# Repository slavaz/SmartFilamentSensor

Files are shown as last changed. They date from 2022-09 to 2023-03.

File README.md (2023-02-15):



Smart Filament Sensor
===

The project describes how to make by your own pretty smart filament sensor for your 3D printer.

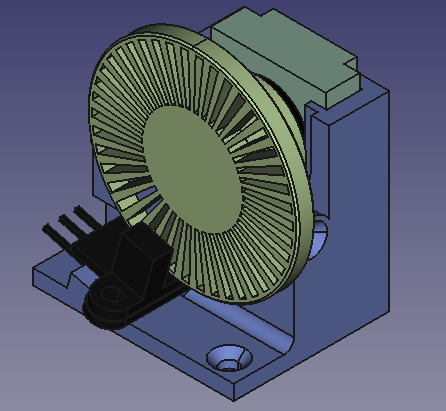
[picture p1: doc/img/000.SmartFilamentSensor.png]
Assembly Engine Part


For getting more information please see [doc/README](doc/README.md) file

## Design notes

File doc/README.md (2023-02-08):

About
===

The Smart Filament Sensor it's just my attempt to implement fully backward compatible sensor with my 'Creality CR10 Smart' 3D printer. I know about existing smart sensors, but almost all of these sensors require flashing by own-compiled firmware with changing sensor settings. My sensor is fully compatible with stock filament sensor and doesn't require any own-compiled firmwares (but you may use the firmwares as well, and without any restrictions).

Main idea
---

So, there is a stock sensor for my printer:

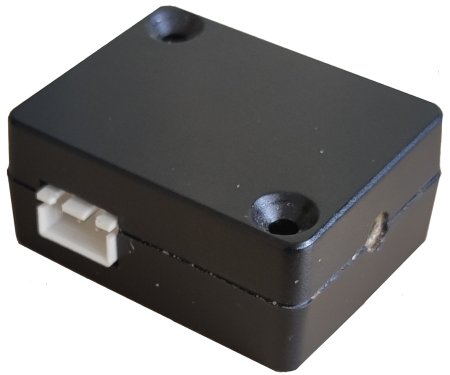
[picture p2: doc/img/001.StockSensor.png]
Stock sensor


The sensor is very simple: has just a microswitch inside and has only one function: to alarm if the microswitch isn't pressed  by a filament. To be honest, the sensor has a optical sensor with some small circuit inside, but it implemented like a simple and stupid micriswitch. In general, it's okay, but there are few cases when it isn't enough:

- The filament may stuck for some reasons. Eg. it may be get tangled in a coil before a sensor or it may be deformed and jammed by feed gear in extruder due to a lot of retractions in small amount of time. In this case the printer continues to print 'in air'. Probably, after some time filament may be  continued to move again  and you will see a lot of 'scary plastic hairs' instead of nice and well-printed model...

- A diameter of the filament may be unstable (especially for self-made filaments like in my case). Or the filament may be severely bent or dented. In this case  microswitch may be switched off due to insufficient filament pressure on the lever and your 3D-printer may think that filament ended, and the printer stucks until you pass 'Changing filement' ceremony. 

So for detecting not only 'filament ended' events, need to recognize only one case: extruder works but filament doesn't move. This case covers all what I need, include 'filament ended' event. And my Smart Filament Sensor recognizes exactly this case.

Prerequirements
===

The Smart Filament Sensor has two movement sensors: one for a filament, and second one - for a motor in extruder. Stock extruder looks like:

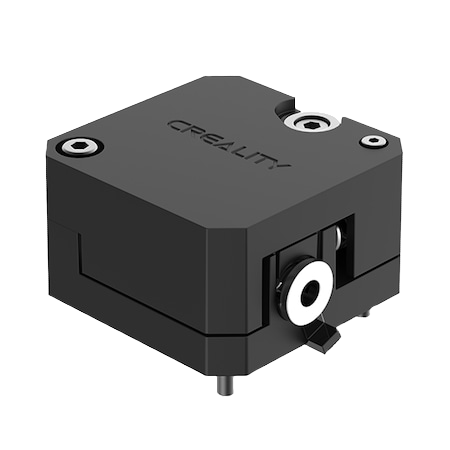
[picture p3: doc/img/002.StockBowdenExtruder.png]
Stock bowden extruder


With this extruder we don't have ability to access to motor shaft (as we need to recognize rotation) - the motor shaft is placed inside fully closed box. So in my case, I've replaced the stock extruder by this:

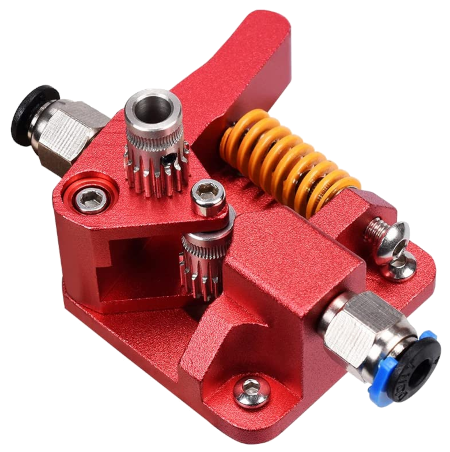
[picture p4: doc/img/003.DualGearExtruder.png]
Dual gear extruder


If you want to buy the same extruder, you may search it in Internet by '[dual gear extruder](https://www.google.com/search?q=dual+gear+extruder)' query. 

The extruder gives us an access to the top of a motor shaft so now it's possible to recognize a rotation of the motor by Smart Filament Sensor.

Requirements
===

Hardware
---

In general, all what I bought is:
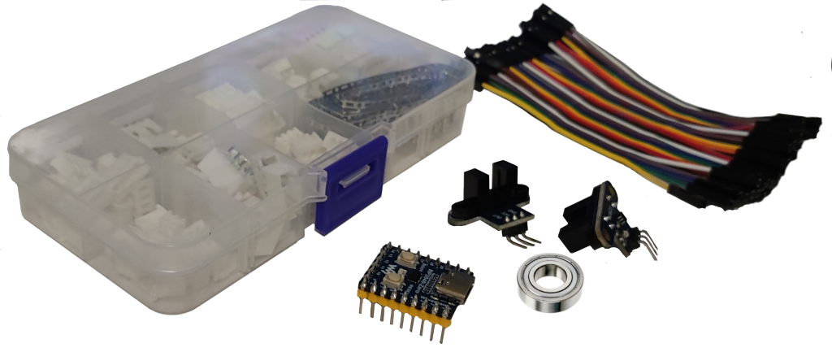
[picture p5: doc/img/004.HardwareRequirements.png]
Hardware Requirements


- RP2040-Zero
- Two movement optical sensors
- a set of wires
- XH2,54 Connector Terminal Kit... to be honest, I only need one 3pin 'mother' connector but it's hard to find just one, so it's easy to buy a kit... maybe it will come in handy in my other projects, yeah
- bearing 625ZZ 5x16x5 mm

All these stuff I bought on AliExpress. I don't sure is it makes sence to post links here as these links may be outdated and you might end up with funny '404 not found' page... but there are links nonetheless:
- https://pl.aliexpress.com/item/32735930193.html
- https://pl.aliexpress.com/item/1005004310502426.html
- https://pl.aliexpress.com/item/32909050779.html
- https://pl.aliexpress.com/item/1005004281549886.html
- https://www.aliexpress.com/item/32719052164.html
  
If any of the links don't work, please let me know via a pull request, huh.

You may already have the following stuff:

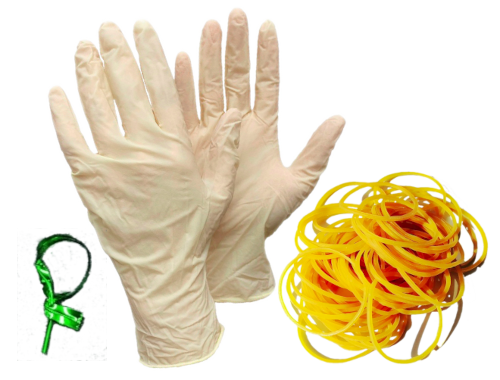
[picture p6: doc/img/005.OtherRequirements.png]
other requirements

- latex medical gloves (you may buy it in any pharmacy or a shop)
- elastic rubber bands (frankly speaking, I never bought it. The rubber bands always present in my house, I don't know from)
- disposable packing wire (we usually throw it in the trash can). It can be found when you buying new electrical products with power wires - the packaging wire prevents twisted wires from unwinding inside the package.

In additional, it would be great if you knew a little about the soldering iron...

And, of course, it would be great if you had a 3D printer as some parts of this project need to be 3D printed.

Software
---

If you only want to assembly the Smart Filament Sensor, then you don't need any additional software. Download only the [latest releases](../releases/)  files and follow [step-by-step](Step-by-step.md) instruction.

If you want to contribute the project (eg, if you want to improve existing source codes or to add support of STM32 or Arduino boards), please follow [Development](Development.md) instructions

Advanages
---
Better control of filament moving

Disadvantages
---

Periodically need to clean up rubber ring as filament may slippage due to lost adgesion. To avoid it, you can use some kind of 'Filament cleaners' like https://www.thingiverse.com/thing:2440593 or https://www.thingiverse.com/thing:190118

TODO
---
To design in FreeCAD nice box for RP2040Zero. As for me, it works as well and functionality is enough, so if you feel that it isn't perfect and you need to show off your 3D-printer with the SmartSensor to you friends- feel free to design the box and create pull request... I'm so lazy to do the last step ;)

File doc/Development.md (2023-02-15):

It's good to see you here at the page as it means, you have posible interest in contributing to the project... but probably not, who knows.
Anyway, at the page you may find instructions how to set up build environment for the project.

Raspberry Pi Pico SDK
===

Install in some folder Pico SDK from here: https://github.com/raspberrypi/pico-sdk

I did it by the command:

`git clone https://github.com/raspberrypi/pico-sdk.git`

and followed instructions from the README.md file of the project.

Nothing hard here, just a reminder: do not forget to define environment variable `PICO_SDK_PATH`

And yet another note: I have Fedora, but instructions from the project describe a way for Debian-based distros, so there are commands to install all needed packages under RPM-based distros:

`sudo dnf install -y cmake arm-none-eabi-binutils-cs  arm-none-eabi-gcc-cs arm-none-eabi-gcc-cs-c++ arm-none-eabi-newlib`

Other tools
===

You also need to install GoogleTest and Freecad.

deb-based distros:
`sudo apt install googletest google-mock libgtest-dev libgmock-dev freecad`

RPM-based distros:

`sudo dnf -y install gtest-devel gmock-devel freecad`

Getting sources
===

It's simply:

`mkdir -p ~/myprojects`

`cd ~/myprojects`

`git clone https://github.com/slavaz/SmartFilamentSensor.git`

`cd SmartFilamentSensor`

Build project
===
`cmake -B build`

`cd build`

`make all test`

If you want to get a tarball with assebmled files, run the command:

`make package`

after it, you will have a tarball into `build/package` folder.

The tarball contains a firmware binary file and STL-files with 3D models.

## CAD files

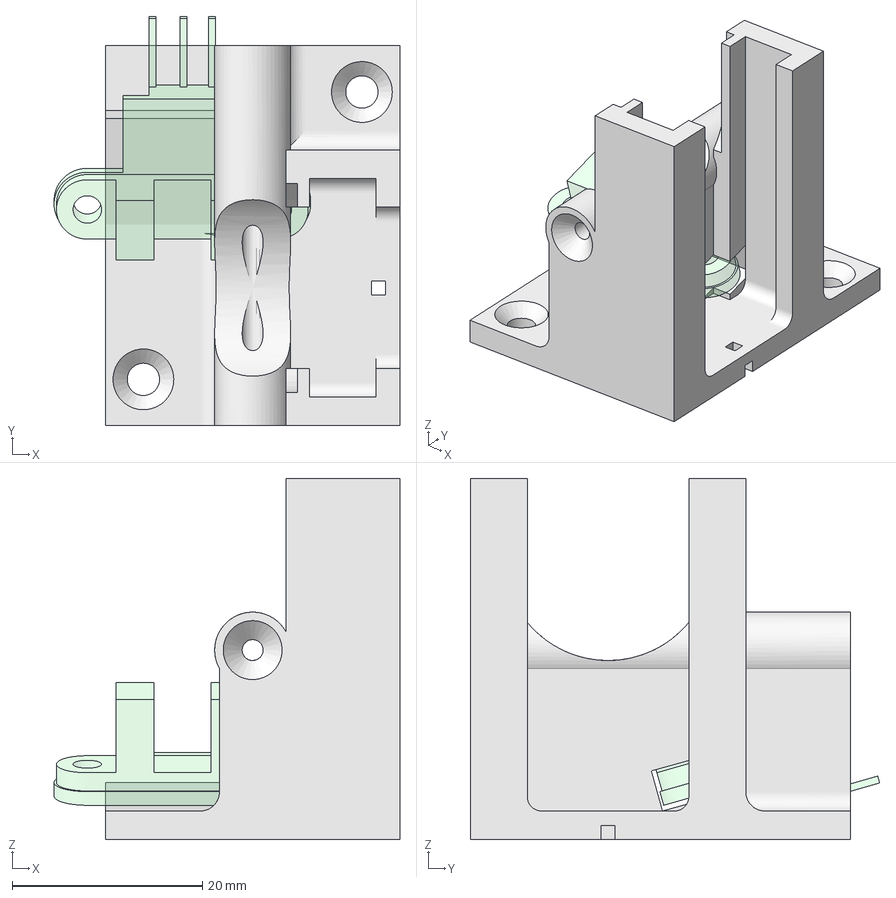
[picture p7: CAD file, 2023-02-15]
3dmodels/CrealityCR10Smart_DualGearExtruder/MainBody.FCStd
36.4 x 43.1 x 38.0 mm
MainBody
MovementSensor (Meshed)

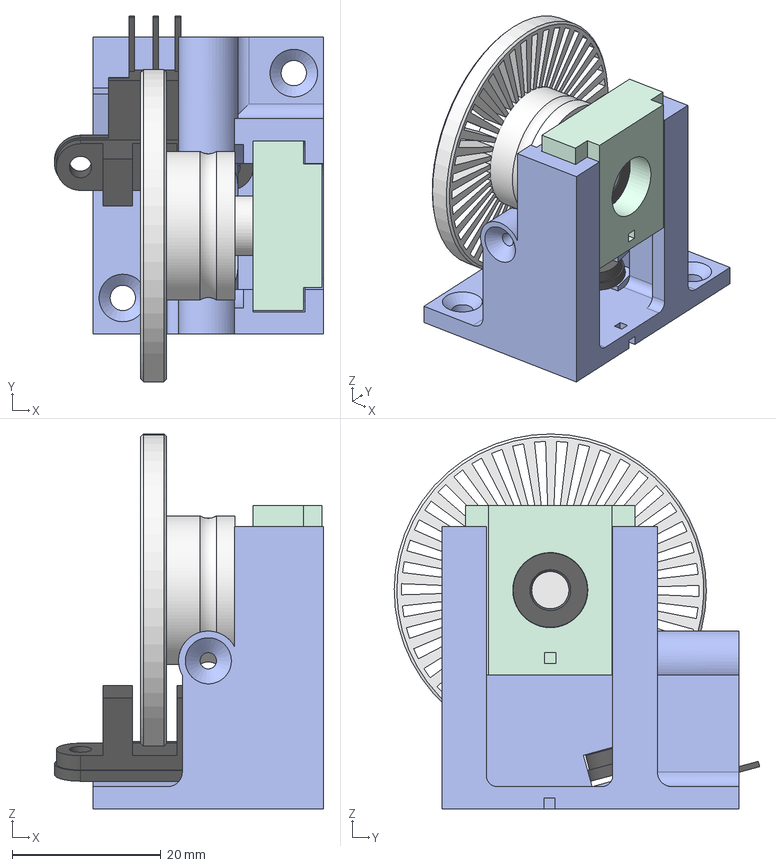
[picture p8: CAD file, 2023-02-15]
3dmodels/CrealityCR10Smart_DualGearExtruder/Assembly-FilamentSensor.FCStd
36.2 x 49.2 x 50.4 mm
MainBody_001
BearingSupport_001
Bearing_001
FilamentWheel_001
MovementSensor_001

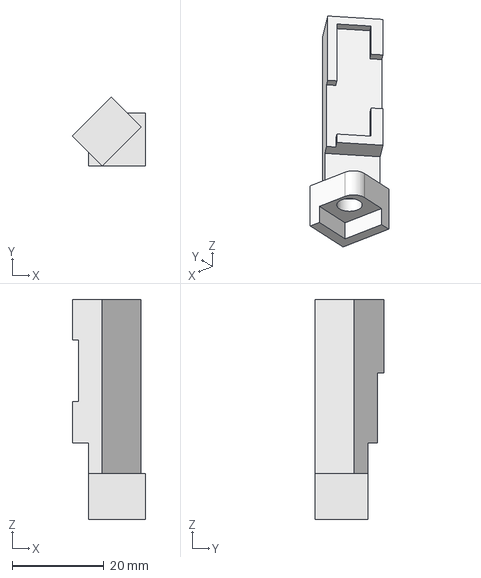
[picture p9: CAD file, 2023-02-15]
3dmodels/CrealityCR10Smart_DualGearExtruder/EngineMainBody.FCStd
16.0 x 15.0 x 48.0 mm

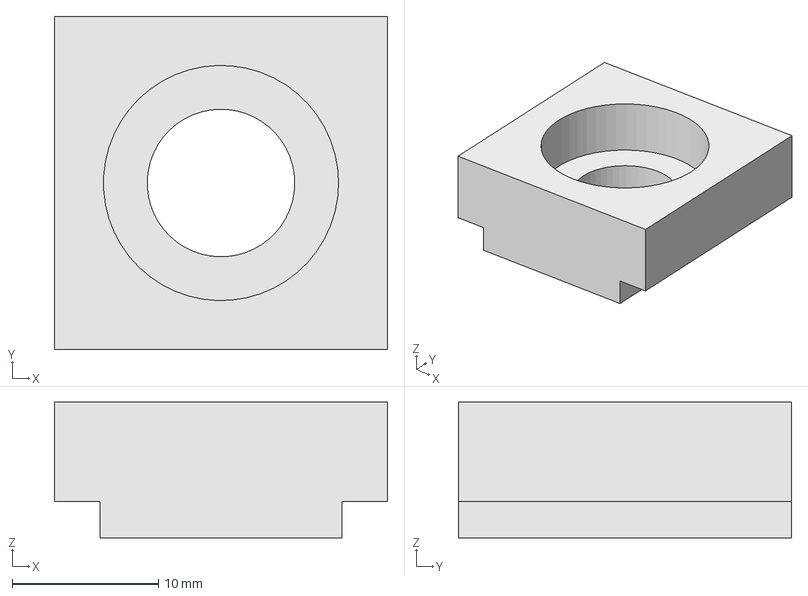
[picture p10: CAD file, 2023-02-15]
3dmodels/CrealityCR10Smart_DualGearExtruder/BearingSupport.FCStd
22.8 x 22.8 x 9.30 mm

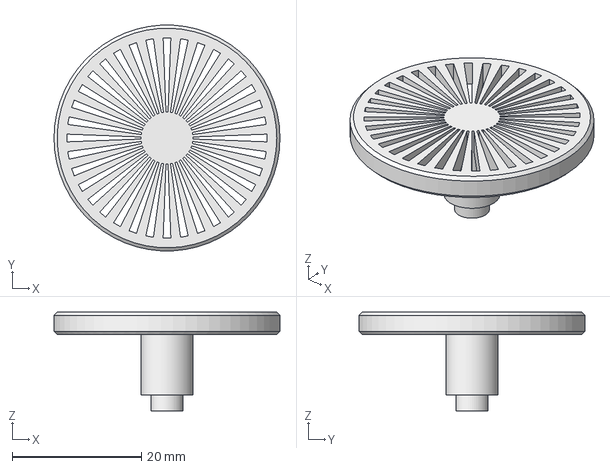
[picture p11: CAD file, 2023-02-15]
3dmodels/CrealityCR10Smart_DualGearExtruder/EngineShaftWheel.FCStd
35.0 x 34.9 x 15.3 mm

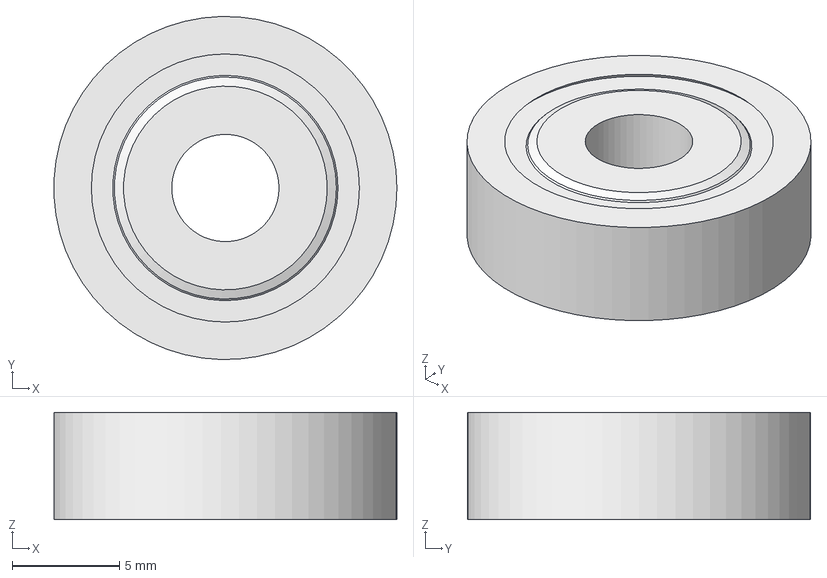
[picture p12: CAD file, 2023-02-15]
3dmodels/CrealityCR10Smart_DualGearExtruder/Bearing.FCStd
16.0 x 16.0 x 5.00 mm

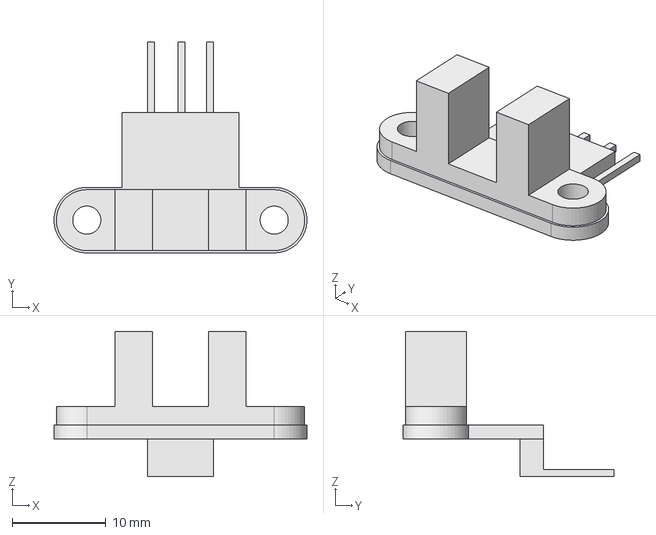
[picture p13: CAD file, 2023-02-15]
3dmodels/CrealityCR10Smart_DualGearExtruder/MovementSensor.FCStd
27.0 x 22.5 x 15.5 mm

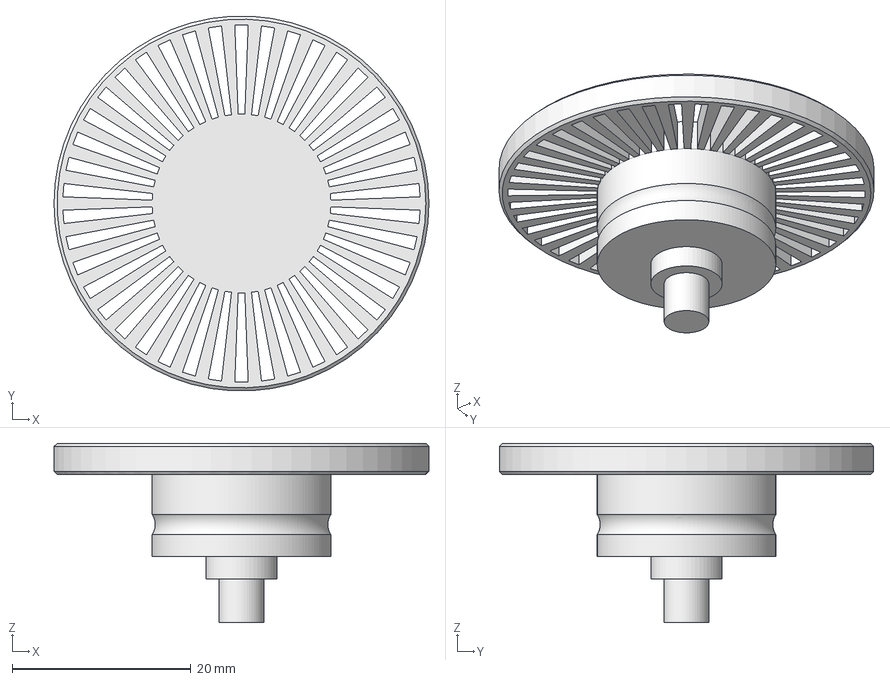
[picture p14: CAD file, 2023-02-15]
3dmodels/CrealityCR10Smart_DualGearExtruder/FilamentWheel.FCStd
42.0 x 41.9 x 20.1 mm

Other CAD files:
3dmodels/CrealityCR10Smart_DualGearExtruder/SharedParameters.FCStd

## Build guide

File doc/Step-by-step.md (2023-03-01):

Step-by-step instruction
===
I suppose, you have bought all needed stuff and downloaded all needed files from the project at this moment, isn't it? If no - please read the [manual](README.md) again more carefully... :)

3D prining
---

So first step is: to 3D-print all parts of the SmartFilamentSensor. I  printed these parts by 0.4 mm nozzle:

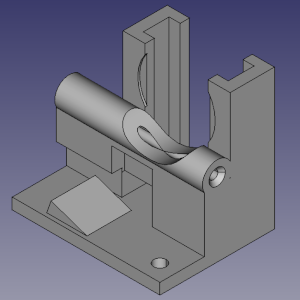
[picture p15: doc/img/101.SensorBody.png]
Sensor body

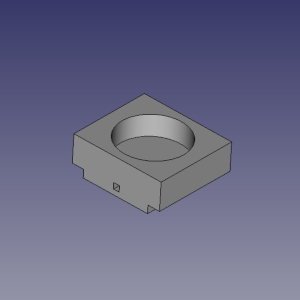
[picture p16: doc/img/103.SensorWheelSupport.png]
Sensor Wheel Support

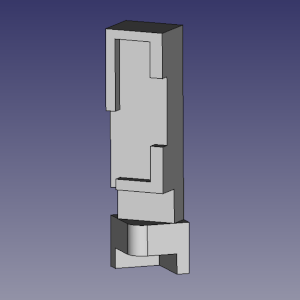
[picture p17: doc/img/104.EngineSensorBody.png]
Engine Sensor Body


and these parts were printed by 0.2 mm nozzle for greater accuracy: 

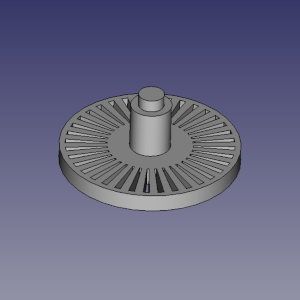
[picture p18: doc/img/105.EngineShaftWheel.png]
Engine Shaft Wheel

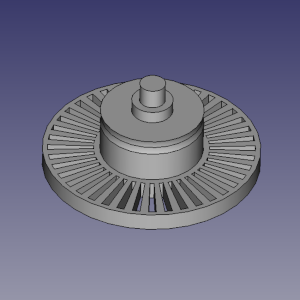
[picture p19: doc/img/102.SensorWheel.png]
Sensor Wheel


Assembling parts
---

Cut by scissors a rubber ring from latex medical gloves:

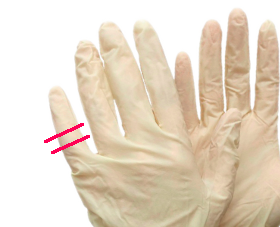
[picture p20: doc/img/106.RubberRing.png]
rubber ring


Stretch the rubber ring over the highlighted surface of sensor wheel:

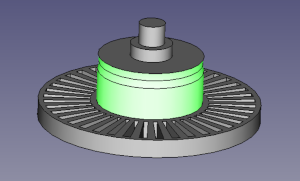
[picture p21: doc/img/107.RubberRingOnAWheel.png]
highlighted surface


this is necessary to prevent filament slippage and better friction.

Put a bearing on the filament wheel. I also put a drop of superglue here, just in case:

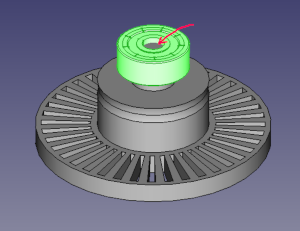
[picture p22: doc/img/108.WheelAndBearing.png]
Wheel And Bearing


Put the bearing into the wheel suport:

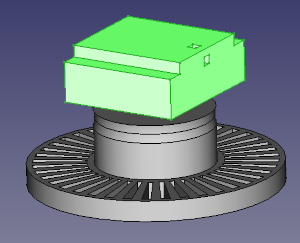
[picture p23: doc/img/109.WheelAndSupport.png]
Wheel And Support


Put one of sensors into main body:

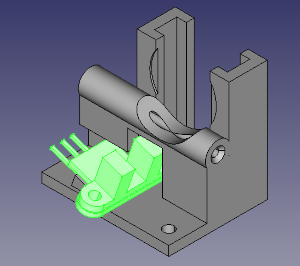
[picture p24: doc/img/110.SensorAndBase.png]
Sensor And Main Body


Put a wheel with support into main body:

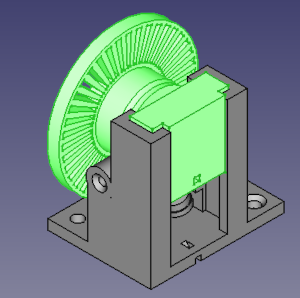
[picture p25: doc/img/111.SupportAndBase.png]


Connect wheel support and main body via rubber ring and wires... well, I don't know how I may draw it, so there is a photo of my sensor:

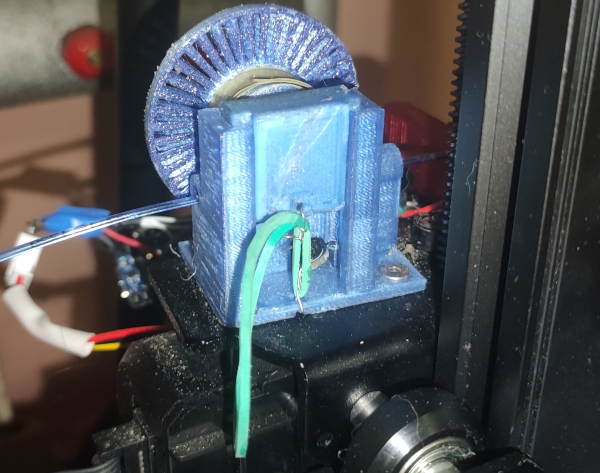
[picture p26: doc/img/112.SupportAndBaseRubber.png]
Sensor And Main Body With Rubber


As you can see, the rubber is stretched and fixed by twisted wires on the support and the body through the holes. Of course, you may use a spring if you have appropriate size, but I don't have one, so  I use a rubber ring and disposable packing wire (peeled of any plastic sheath).

Put second movement sensor on the engine body. You may use a drop of thermoglue or super-glue for this:

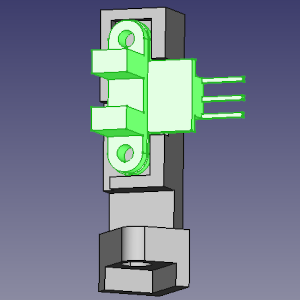
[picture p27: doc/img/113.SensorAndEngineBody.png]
Sensor And Engine Body


Soldering
---
Well, frankly speaking, soldering is optional and you may use wires with connectors, but from my point of view, it may produce a lot of issues with connections and as result, incorrect and unstable behaviour of SmartSensor... so I'd like to prefer soldering.

Connect all elements regarding to the scheme:

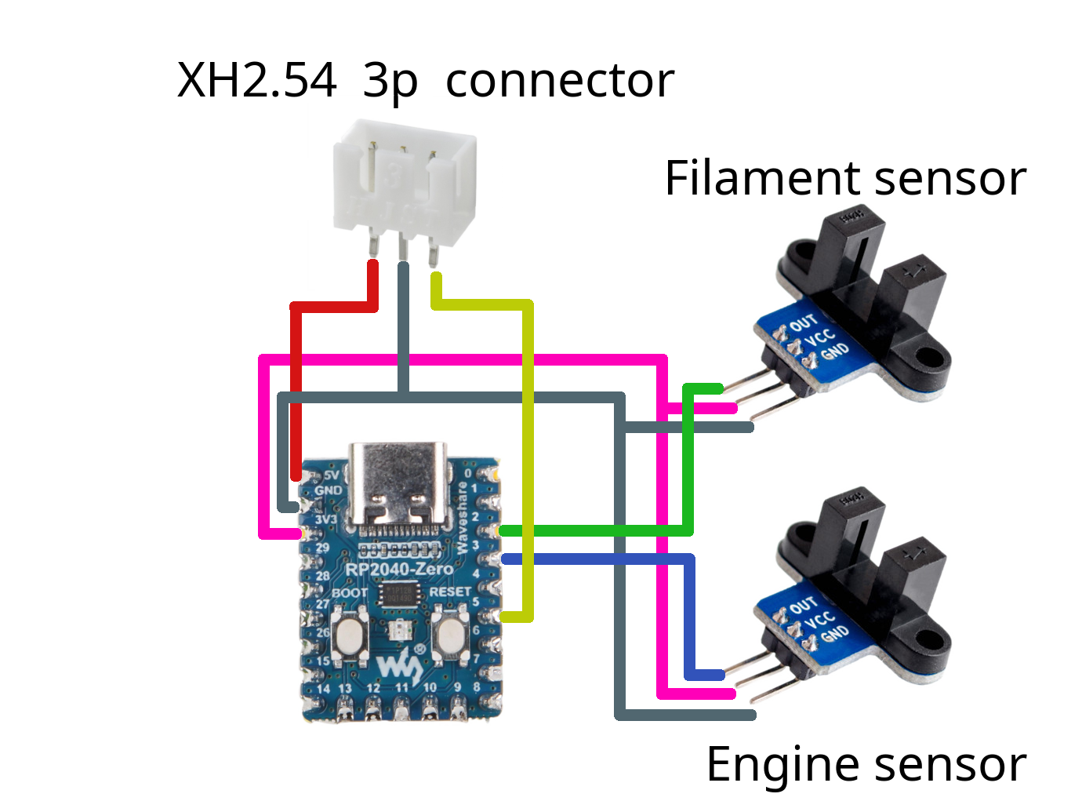
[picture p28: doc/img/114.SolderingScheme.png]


Flashing firmware
---
Connect RP2040Zero to your PC via USB cable. Press 'RESET' button on the plate, don't release the button and press 'BOOT' button so you should have two buttons pressed. Release 'RESET' button and next release 'BOOT' button. f you did everything correctly, your RP2040Zero will be visible for your PC as an USB flash drive. Copy firmware bin-file to the 'usb stick'. After it, the drive will be disconnected and firmware successfully flashed to the plate.

Final steps
---
On the final step, need to put Engine wheel on a motor shaft and put 'engine sensor body' with a sensor to body of extruder using few drop of superglue. It should looks like:

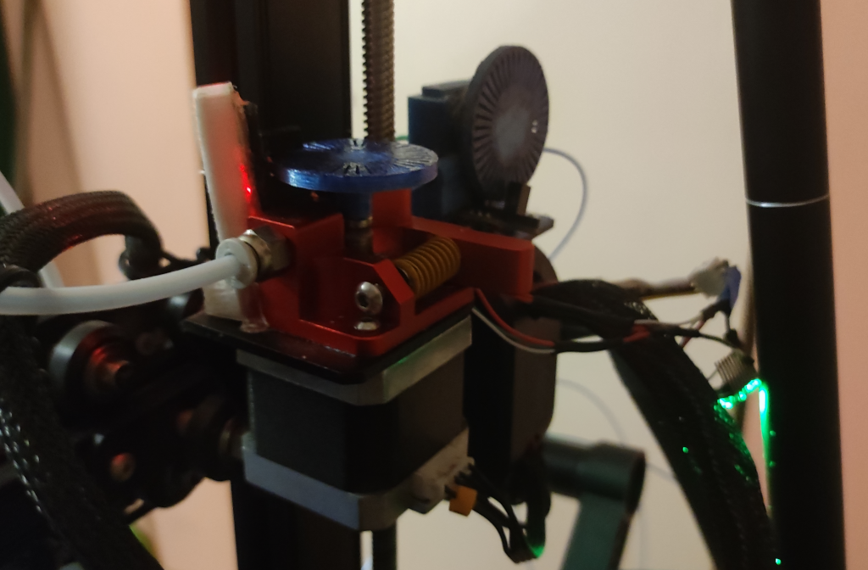
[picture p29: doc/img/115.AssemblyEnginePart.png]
Assembly Engine Part


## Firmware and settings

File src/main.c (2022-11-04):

/*
This file is part of the SmartFilamentSensor distribution
Copyright (C) 2022 Slava Zanko

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
You should have received a copy of the GNU General Public License
along with this program.  If not, see <http://www.gnu.org/licenses/>.
*/

#include <stdio.h>
#include "pico/stdlib.h"

#include "movement_sensor.h"
#include "rgb_led.h"

/*** file scope macro definitions ****************************************************************/

#define SENSOR_FILAMENT_PIN 2
#define SENSOR_ENGINE_PIN 3
#define ALARM_PIN 5
#define RGB_LED_PIN 16

#define DELAY_SENSOR_READING_MILLISEC 3000

/*** file scope type declarations ****************************************************************/

/*** file scope variables ************************************************************************/

static movement_sensor_t filament_sensor;
static movement_sensor_t engine_sensor;
static rgb_led_t rgb_led;

/*** global variables ****************************************************************************/

/*** file scope functions ************************************************************************/
/* --------------------------------------------------------------------------------------------- */

static void alarm_init()
{
    gpio_init(ALARM_PIN);
    gpio_set_dir(ALARM_PIN, GPIO_OUT);
}

/* --------------------------------------------------------------------------------------------- */

static void alarm_if(const bool alarm_flag)
{
    gpio_put(ALARM_PIN, alarm_flag);

    rgb_led__set(&rgb_led, alarm_flag ? &RGB_RED : &RGB_GREEN);
}

/* --------------------------------------------------------------------------------------------- */

static void setup()
{
    stdio_init_all();

    rgb_led__init(&rgb_led, pio0, RGB_LED_PIN);
    rgb_led__set(&rgb_led, &RGB_BLUE);

    movement_sensor__init(&filament_sensor, SENSOR_FILAMENT_PIN);
    movement_sensor__set_reading_delay(&filament_sensor, DELAY_SENSOR_READING_MILLISEC);

    movement_sensor__init(&engine_sensor, SENSOR_ENGINE_PIN);
    movement_sensor__set_reading_delay(&engine_sensor, DELAY_SENSOR_READING_MILLISEC);

    alarm_init();
}

/* --------------------------------------------------------------------------------------------- */

static void loop()
{
    bool filament_moved;
    bool engine_moved;

    filament_moved = movement_sensor__moved(&filament_sensor);
    engine_moved = movement_sensor__moved(&engine_sensor);

    printf("Filament: %d, engine: %d, alarm: %d\n", filament_moved, engine_moved, engine_moved && !filament_moved);

    alarm_if(engine_moved && !filament_moved);

    sleep_ms(10);
}

/* --------------------------------------------------------------------------------------------- */
/*** public functions ****************************************************************************/
/* --------------------------------------------------------------------------------------------- */

int main()
{
    setup();

    while (1)
    {
        loop();
    }

    return 0;
}

/* --------------------------------------------------------------------------------------------- */

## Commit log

2022-09-27 Add empty FreeCad source file
    [SmartFilamentSensor.FCStd]
2022-11-04 Add 3D models for CR10Smart
    [SmartFilamentSensor.FCStd]
2022-11-04 Fixies after first run
    [main.c]
2022-11-04 A little code refacroring and increasing lateny delay for reading sensors to 3 seconds
2022-11-04 Refactoring: create separate classes for controlling events from sensors and for alerting
2022-11-04 Tuning initial values for sensors
2022-11-21 Add SensorManagement class
2022-11-22 Reimplement logic to use more clear "State mashine" pattern. Add Timer class for handling timeouts
2022-11-28 Add suspection_on_error stage. Add a commands to switch on internal pull-down resistors on pins to avoid ocassional error reporting
    [movement_sensor.cpp, pin_output.cpp]
2023-01-30 Add tests for Timer class
2023-02-04 add tests for SensorManagement class. Improove other tests
2023-02-07 Add cmake targets for build STL files from FreeCAD file
2023-02-15 Split one big FreeCad file to a set of smaller files
    [Assembly-FilamentSensor.FCStd, Bearing.FCStd, BearingSupport.FCStd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]
2023-02-27 Tests refactoring: use standard Google Mocks for mocking PICO library calls

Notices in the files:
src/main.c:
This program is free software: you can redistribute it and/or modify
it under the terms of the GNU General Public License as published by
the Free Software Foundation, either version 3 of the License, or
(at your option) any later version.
